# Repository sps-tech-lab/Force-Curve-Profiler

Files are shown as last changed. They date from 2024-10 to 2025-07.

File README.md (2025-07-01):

# Force-curve meter for silicone membrane buttons evaluation



Force-curve measurement is a technique used to assess the mechanical properties of materials, such as silicon buttons, by measuring the relationship between applied force and the resulting deformation. For silicon buttons, this method typically involves applying a controlled force to the surface of the button using a probe or actuator and recording the corresponding displacement. The resulting force-displacement curve provides insights into the material's stiffness, elasticity, and mechanical response under load. It helps in determining key parameters like actuation force, tactile feedback, and wear characteristics, which are crucial for quality control and design optimization of silicon buttons used in electronics.

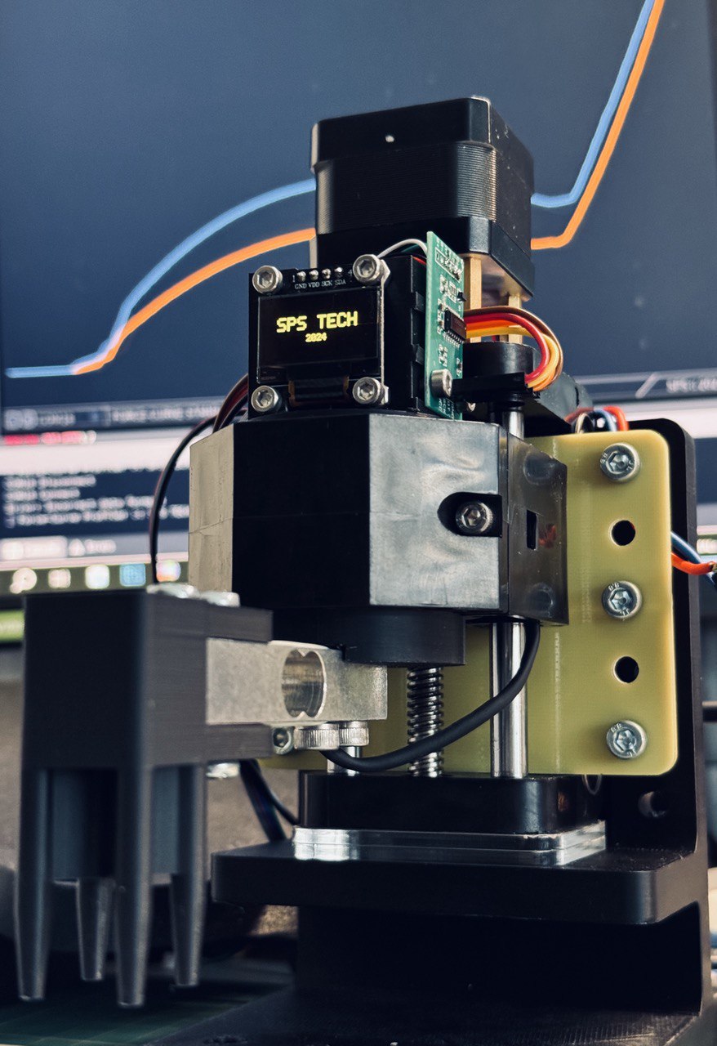
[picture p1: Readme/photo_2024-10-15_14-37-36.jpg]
Appearence


### Features

- Zero Point auto-detect
- CSV file auto-save `(/data/scans/)`
- Last scan shadow reference on the screen `(/data/ref_scan.csv)`
- Generated scans can be easily opened in different viewers `(note the \t separator)`
- Two types of probes `(see. /3d_models/)`

### Hardware

-   Stepper motor
-   16x micro steps stepper motor driver
-   Weight sensor 1kG
-   HX711 a precision 24-bit analog-to-digital converter (ADC) designed for weigh scales.
-   OLED SSD1306 based display 128x64
-   Arduino Nano
-   Limit switch (for home parking)
-   Button (for user interactions)

```
Board                Component           Pin on Component
---------------      ------------------  ----------------
   5V                VCC (All modules)   VCC / +5V
   GND               GND (All modules)   GND
   A4 (SDA)          OLED SDA            SDA
   A5 (SCL)          OLED SCL            SCL
   D3                HX711 DOUT          DOUT
   D4                HX711 SCK           SCK
   D8                Stepper DIR         DIR
   D9                Stepper STEP        STEP
   D10               Stepper SLEEP       SLEEP
   A0                Home contact        → one side to A0, other side to GND
   A1                Control Button      → one side to A1, other side to GND
   D13 (LED_BUILTIN) Status LED          LED (built‑in)
```

### Required Libraries
- **Arduino** (built-in)
- **Wire** (built-in)
- **BasicStepperDriver** by simplelabs (install via Library Manager or https://github.com/simplelabs/BasicStepperDriver)
- **HX71*1** by bogde (install via Library Manager or https://github.com/bogde/HX711)
- **GyverOLED** by GYVER (install via Library Manager or https://github.com/GyverLibs/GyverOLED)

### Scan example
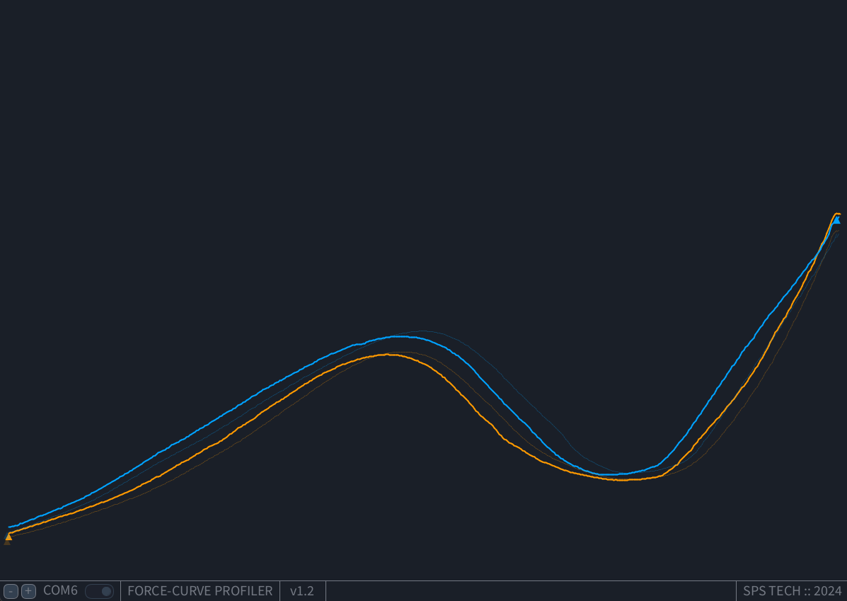
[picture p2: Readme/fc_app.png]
PC app


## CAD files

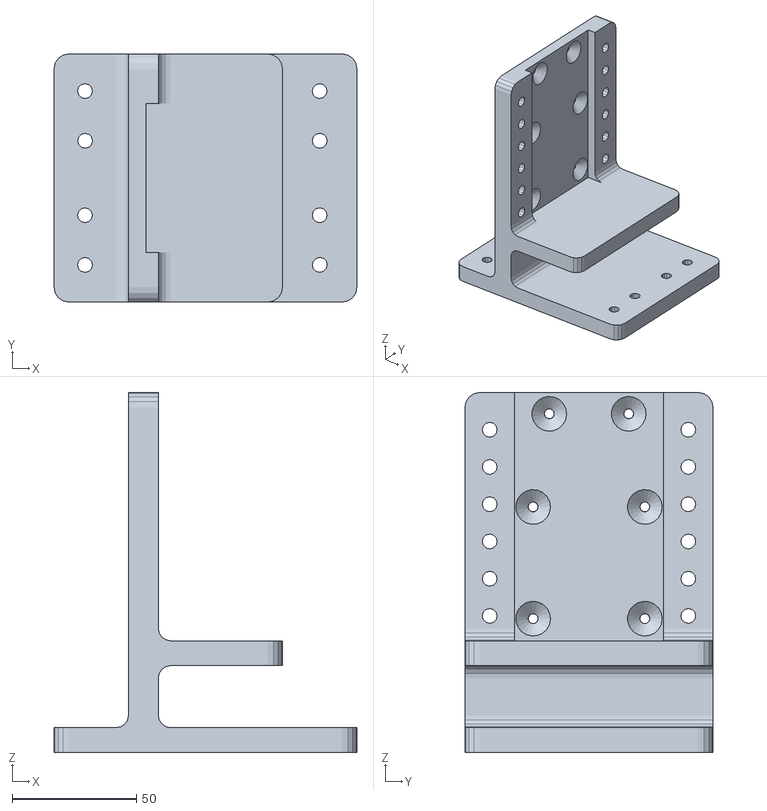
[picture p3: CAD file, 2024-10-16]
3d_models/ButtonProfiler_stand.stl
122.0 x 100.0 x 145.0

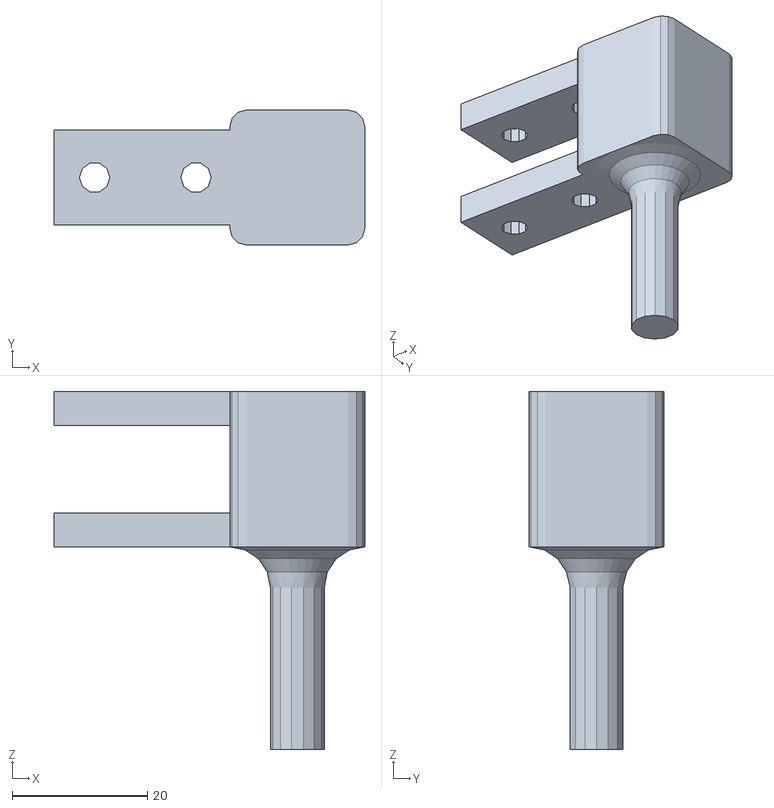
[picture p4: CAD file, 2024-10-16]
3d_models/ButtonProfiler_probe_pin.stl
46.0 x 20.0 x 53.0

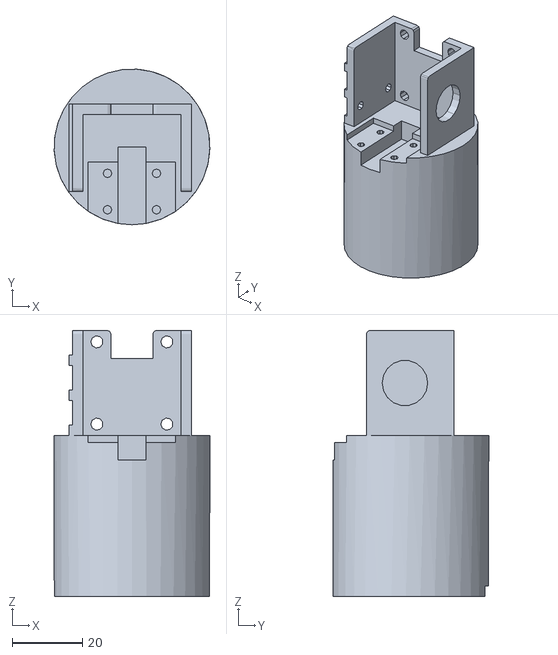
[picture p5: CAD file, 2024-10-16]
3d_models/ButtonProfiler.stl
44.5 x 44.5 x 76.0

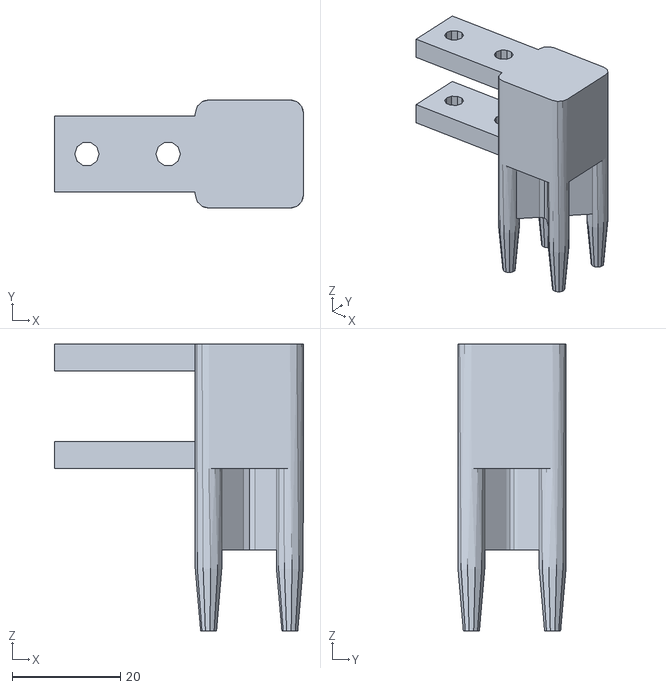
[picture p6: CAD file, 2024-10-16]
3d_models/ButtonProfiler_probe.stl
46.0 x 20.0 x 53.0

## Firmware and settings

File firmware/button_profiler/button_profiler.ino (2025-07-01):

#include <Arduino.h>
#include "BasicStepperDriver.h"
#include "HX711.h"
#include <stdlib.h>
#include <GyverOLED.h>
#include <avr/wdt.h>

// -----------------------------------------------------------------------------
// Configuration Constants
// -----------------------------------------------------------------------------

//Config
#define SCAN_DEPTH  (500)           //Scan Depth (Hardcoded in PC App!)

// Stepper motor configuration
#define MOTOR_STEPS 200
#define RPM         120
#define DIR         8
#define STEP        9
#define SLEEP       10
#define MICROSTEPS  16

// HX711 load cell pins
const int LOADCELL_DOUT_PIN = 3;
const int LOADCELL_SCK_PIN  = 4;

/// OLED display template
using Display = GyverOLED<SSD1306_128x64, OLED_BUFFER>;

// Button and sync input pins
#define HOME_PIN A0
#define BUTN_PIN A1

// Onboard LED pin for feedback
#define PIN_STATUS_LED LED_BUILTIN


// -----------------------------------------------------------------------------
// State and progress variables
// -----------------------------------------------------------------------------

//Progress
uint16_t      progress = 0;
uint16_t      percent = 0;
bool          break_scan = false;

// -----------------------------------------------------------------------------
// Global Objects
// -----------------------------------------------------------------------------

BasicStepperDriver stepper(MOTOR_STEPS, DIR, STEP, SLEEP);
Display oled;
HX711 scale;

// -----------------------------------------------------------------------------
// 3D cube screensaver
// -----------------------------------------------------------------------------

double vectors[8][3] = {{ 20,  20, 20}, 
                        { -20, 20, 20},
                        { -20,-20, 20},
                        { 20, -20, 20},
                        { 20,  20, -20},
                        {-20,  20, -20},
                        {-20, -20, -20},
                        { 20, -20, -20}};
double perspective = 100.0f;
int    deltaX, deltaY, deltaZ, iter = 0;

// -----------------------------------------------------------------------------
// Setup
// -----------------------------------------------------------------------------
void setup() {
    Serial.begin(115200);
    Serial.println("Force-Curve Profiler :: SPS TECH :: 2024");

    //Input
    pinMode(HOME_PIN, INPUT_PULLUP);
    pinMode(BUTN_PIN, INPUT_PULLUP);

    // initialize the LED pin as an output:
    pinMode(PIN_STATUS_LED, OUTPUT);

    //Init HX711
    scale.begin(LOADCELL_DOUT_PIN, LOADCELL_SCK_PIN);
    scale.set_scale(2280.f);       // this value is obtained by calibrating the scale with known weights; see the README for details
    scale.tare();                  // reset the scale to 0
  
    //Stepper
    stepper.begin(RPM, MICROSTEPS);
    stepper.setEnableActiveState(LOW);

    //Display
    oled.init();
    Wire.setClock(800000L);

    while(digitalRead(BUTN_PIN) == LOW){
        oled.clear();
        oled.setScale(2);
        oled.setCursorXY(42, 25);
        oled.print("v1.2");
        oled.update();
    }

    oled.setScale(2);
    oled.setCursorXY(15, 20);
    oled.print("SPS TECH");
    oled.setScale(1);
    oled.setCursorXY(50, 40);
    oled.print("2024");
    oled.setScale(1);
    oled.update();
    
    delay(2000);

    park_home();
}

// -----------------------------------------------------------------------------
// Main Loop
// -----------------------------------------------------------------------------
void loop() {

    Serial.println("START");
    break_scan = false;

    //Wait for start
    while(digitalRead(BUTN_PIN) == HIGH){
      screensaver();
    }

    oled.clear();
    oled.setScale(2);
    oled.setCursorXY(40, 20);
    oled.print("TARE");
    oled.update();
    scale.tare();

    //Find start position
    stepper.enable();
    start_probe();
    stepper.disable();

    //Prepare allowed
    oled.setScale(2);
    oled.setCursorXY(10, 20);
    oled.print("GET READY");
    oled.update();
    delay(100);

    //Scan allowed
    //Tare double check
    if(scale.get_units(10) < 0){
      oled.clear();
      oled.setScale(2);
      oled.setCursorXY(40, 20);
      oled.print("TARE");
      oled.update();
      scale.tare();
      delay(100);
    }

    progress = 0;
    stepper.enable();

    //Press
    for(uint16_t steps = 0; steps<SCAN_DEPTH; steps++){

      stepper.rotate(-1);

      float force = scale.get_units(1);
      if(force < 0) force = 0;

      percent = map(progress++, 0, 1000, 0, 99);

      Serial.print(steps);
      Serial.print("\t");
      Serial.print(force);
      Serial.println("\tPRESS");

      oled.clear();
      oled.setScale(1);
      oled.setCursorXY(0, 0);
      oled.print(percent);
      if(percent <10){
        oled.setCursorXY(8, 0);
      }else{
        oled.setCursorXY(15, 0);
      }
      oled.print("%");

      oled.setScale(3);
      if(force < 10 ){
        oled.setCursorXY(30, 20);
      }else if(force > 100 ){
        oled.setCursorXY(10, 20);
      }else{
        oled.setCursorXY(20, 20);
      }
      oled.print(force);
      oled.update();

      if( digitalRead(BUTN_PIN) == LOW ){
        break_scan = true;
        break;
      }
    }

    //Release
    if( break_scan == false ){
      for(uint16_t steps = SCAN_DEPTH; steps>0; steps--){

        stepper.rotate(1);

        float force = scale.get_units(1);
        if(force < 0) force = 0;

        percent = map(progress++, 0, 1000, 0, 99);

        Serial.print(steps);
        Serial.print("\t");
        Serial.print(force);
        Serial.println("\tRELEASE");

        oled.clear();
        oled.setScale(1);
        oled.setCursorXY(0, 0);
        oled.print(percent);
        if(percent <10){
          oled.setCursorXY(8, 0);
        }else{
          oled.setCursorXY(15, 0);
        }
        oled.print("%");

        oled.setScale(3);
        if( force < 10 ){
          oled.setCursorXY(30, 20);
        }else if( force > 100 ){
          oled.setCursorXY(10, 20);
        }else{
          oled.setCursorXY(20, 20);
        }
        oled.print(force);
        oled.update();

        if( digitalRead(BUTN_PIN) == LOW ){
          break_scan = true;
          break;
        }
      }
    }

    if( break_scan == false ){
      Serial.println("FINISH");
    }

    park_home();
    stepper.disable();
    oled.setScale(2);
    oled.setCursorXY(40, 20);
    oled.print("TARE");
    oled.update();
    scale.tare();
    oled.clear();
    oled.update(); 
    
    while(digitalRead(BUTN_PIN) != LOW){
      screensaver();
    };
}

// -----------------------------------------------------------------------------
// Motor Actions
// -----------------------------------------------------------------------------
/**
 * @brief Performs homing routine for the stepper motor.
 */
void park_home(){
    oled.clear();
    oled.setScale(2);
    oled.setCursorXY(40, 20);
    oled.print("HOME");
    oled.update();

    stepper.enable();
    while(digitalRead(HOME_PIN) == HIGH){
        stepper.rotate(1);
        digitalWrite(PIN_STATUS_LED, HIGH);
        digitalWrite(PIN_STATUS_LED, LOW);
    }
    stepper.disable();
    oled.clear();
    oled.update(); 
}

/**
 * @brief Probe nearest surface to find "Zero Point"
 */
void start_probe(){

    float force;

    oled.clear();
    oled.setScale(2);
    oled.setCursorXY(40, 20);
    oled.print("PROBE");
    oled.update();

    stepper.enable();
    force = scale.get_units(1);
    while(force < 10) {
        stepper.rotate(-100);
        force = scale.get_units(1);
        if(force < 0) force = 0;
    }
    stepper.rotate(150);
    while(force < 1) {
        stepper.rotate(-1);
        force = scale.get_units(1);
        if(force < 0) force = 0;
    }
    stepper.rotate(50);
    stepper.disable();

    oled.clear();
    oled.update(); 
}

// -----------------------------------------------------------------------------
//Screensaver functions
// -----------------------------------------------------------------------------
/**
 * @brief Run screensaver
 */
void screensaver(){
  oled.clear();
  oled.home();
  drawVectors();
  if (iter == 0) {
    deltaX = random(7) - 3;
    deltaY = random(7) - 3;
    deltaZ = random(7) - 3;
    iter   = random(250) + 5;
  }
  rotateX(deltaX);
  rotateY(deltaY);
  rotateZ(deltaZ);
  iter--;
  oled.update();
}

/**
 * @brief Translations
 */
int translateX(double x, double z) {
  return (int)((x + 64) + (z * (x / perspective)));
}
int translateY(double y, double z) {
  return (int)((y + 32) + (z * (y / perspective)));
}

/**
 * @brief Rotations
 */
void rotateX(int angle) {
  double rad, cosa, sina, Yn, Zn;
  rad = angle * PI / 180;
  cosa = cos(rad);
  sina = sin(rad);
  for (int i = 0; i < 8; i++) {
    Yn = (vectors[i][1] * cosa) - (vectors[i][2] * sina);
    Zn = (vectors[i][1] * sina) + (vectors[i][2] * cosa);
    vectors[i][1] = Yn;
    vectors[i][2] = Zn;
  }
}
void rotateY(int angle) {
  double rad, cosa, sina, Xn, Zn;
  rad = angle * PI / 180;
  cosa = cos(rad);
  sina = sin(rad);
  for (int i = 0; i < 8; i++)
  {
    Xn = (vectors[i][0] * cosa) - (vectors[i][2] * sina);
    Zn = (vectors[i][0] * sina) + (vectors[i][2] * cosa);
    vectors[i][0] = Xn;
    vectors[i][2] = Zn;
  }
}
void rotateZ(int angle) {
  double rad, cosa, sina, Xn, Yn;
  rad = angle * PI / 180;
  cosa = cos(rad);
  sina = sin(rad);
  for (int i = 0; i < 8; i++) {
    Xn = (vectors[i][0] * cosa) - (vectors[i][1] * sina);
    Yn = (vectors[i][0] * sina) + (vectors[i][1] * cosa);
    vectors[i][0] = Xn;
    vectors[i][1] = Yn;
  }
}

/**
 * @brief Vectors
 */
void drawVectors() {
  oled.line(translateX(vectors[0][0], vectors[0][2]), translateY(vectors[0][1], vectors[0][2]), translateX(vectors[1][0], vectors[1][2]), translateY(vectors[1][1], vectors[1][2]));
  oled.line(translateX(vectors[1][0], vectors[1][2]), translateY(vectors[1][1], vectors[1][2]), translateX(vectors[2][0], vectors[2][2]), translateY(vectors[2][1], vectors[2][2]));
  oled.line(translateX(vectors[2][0], vectors[2][2]), translateY(vectors[2][1], vectors[2][2]), translateX(vectors[3][0], vectors[3][2]), translateY(vectors[3][1], vectors[3][2]));
  oled.line(translateX(vectors[3][0], vectors[3][2]), translateY(vectors[3][1], vectors[3][2]), translateX(vectors[0][0], vectors[0][2]), translateY(vectors[0][1], vectors[0][2]));
  oled.line(translateX(vectors[4][0], vectors[4][2]), translateY(vectors[4][1], vectors[4][2]), translateX(vectors[5][0], vectors[5][2]), translateY(vectors[5][1], vectors[5][2]));
  oled.line(translateX(vectors[5][0], vectors[5][2]), translateY(vectors[5][1], vectors[5][2]), translateX(vectors[6][0], vectors[6][2]), translateY(vectors[6][1], vectors[6][2]));
  oled.line(translateX(vectors[6][0], vectors[6][2]), translateY(vectors[6][1], vectors[6][2]), translateX(vectors[7][0], vectors[7][2]), translateY(vectors[7][1], vectors[7][2]));
  oled.line(translateX(vectors[7][0], vectors[7][2]), translateY(vectors[7][1], vectors[7][2]), translateX(vectors[4][0], vectors[4][2]), translateY(vectors[4][1], vectors[4][2]));
  oled.line(translateX(vectors[0][0], vectors[0][2]), translateY(vectors[0][1], vectors[0][2]), translateX(vectors[4][0], vectors[4][2]), translateY(vectors[4][1], vectors[4][2]));
  oled.line(translateX(vectors[1][0], vectors[1][2]), translateY(vectors[1][1], vectors[1][2]), translateX(vectors[5][0], vectors[5][2]), translateY(vectors[5][1], vectors[5][2]));
  oled.line(translateX(vectors[2][0], vectors[2][2]), translateY(vectors[2][1], vectors[2][2]), translateX(vectors[6][0], vectors[6][2]), translateY(vectors[6][1], vectors[6][2]));
  oled.line(translateX(vectors[3][0], vectors[3][2]), translateY(vectors[3][1], vectors[3][2]), translateX(vectors[7][0], vectors[7][2]), translateY(vectors[7][1], vectors[7][2]));
}

// //SW Reboot
// void reboot() {
//   wdt_disable();
//   wdt_enable(WDTO_15MS);
//   while (1) {}
// }

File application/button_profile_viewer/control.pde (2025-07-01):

//Colors
color       bgcolor     = color( 26, 31, 40 );
color       trcolor     = color( 230, 219, 116, 75 );
color       cncolor     = color( 117, 113, 94 );
color       txcolor     = #747983;
color       orng_out    = #f89300;
color       blue_out    = #0083cd;

/**
  **************************************************************************************************
  * @brief      My watermark
  **************************************************************************************************
**/
void control_watermark(){ 
  //Draw watermark
  textSize(20);
  fill(bgcolor);
  stroke(txcolor);
  textAlign(RIGHT, CENTER);
  rect( 0, height-30, width, 30);
  fill(txcolor);
  text("SPS TECH :: 2024", width-10, height-16);
  line(width-160, height, width-160, height-30);
}

/**
  **************************************************************************************************
  * @brief      Draw a group of serial control buttons
  **************************************************************************************************
**/
void control_group(int x, int y) 
{
  fill(bgcolor);
  stroke(txcolor);
  rect( x-1, y-30, 170+1, 50);
  line(x+395, height, x+395, height-30);
  line(x+460, height, x+460, height-30);
  

  if(Button("", x+30, y-25, 20, 20, 7)){
    btn_click("+");
  }
  if(Button("", x+5, y-25, 20, 20, 7)){
    btn_click("-");
  }
  

  serial.set(Toggle(serial.get(), x+120, y-25, 40, 20 ));
  textSize(20);
  fill(txcolor);
  textAlign(LEFT, CENTER);
  text("FORCE-CURVE PROFILER", x+180, y-16);
  text("v1.2", x+410, y-16);
  
  textSize(20);
  fill(txcolor);
  textAlign(LEFT, CENTER);
  text("+", x+35, y-16);
  text("-", x+12, y-16);

  textAlign(CENTER, CENTER);
  text(serial.get_name(), x+85, y-17);
  
}

/**
  **************************************************************************************************
  * @brief      Button click handler
  **************************************************************************************************
**/
void btn_click(String dir){
  if( dir == "+" ){
    serial.inc();
  }else{
    serial.dec();
  }
}

/**
  **************************************************************************************************
  * @brief      "new Serial()" cаll wrap
  **************************************************************************************************
**/
Serial open_port(String port_name, int port_speed){
  Serial res = null;
  try {
    res = new Serial(this, port_name, port_speed);
  }catch(Exception e){
    println("Error opening serial port " + port_name + ": " + e.getMessage());
  }
  return res;
}

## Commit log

2024-10-16 add models and update readme
    [ButtonProfiler.stl, ButtonProfiler_probe.stl, ButtonProfiler_probe_pin.stl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]
2025-07-01 major app & fw update
    [ref_scan.csv]
